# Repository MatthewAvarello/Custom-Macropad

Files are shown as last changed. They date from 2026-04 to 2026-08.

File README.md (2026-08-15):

# Matthew's Lovely Macropad
My macropad is a 9 key macropad with a rotary encoder and an OLED screen! It uses KMK Firmware
## PCB
### Schematic:
The 9 keys are positioned in a 3x3 matrix, saving 3 gpio pins for other use

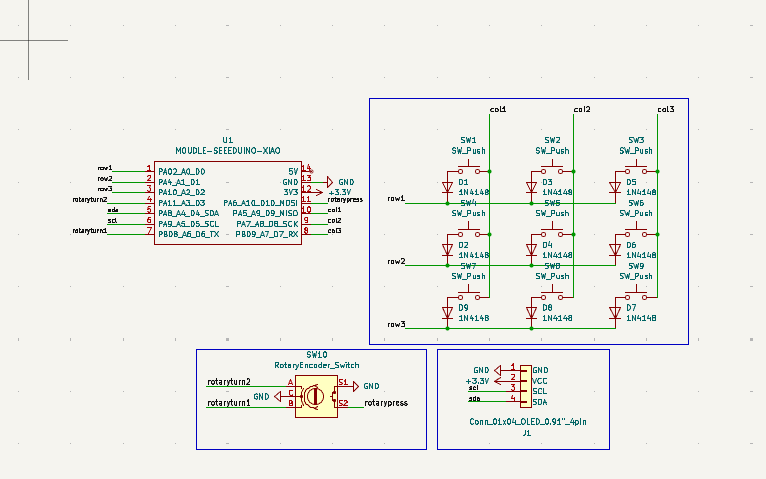
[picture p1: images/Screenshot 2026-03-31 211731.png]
Schematic

### PCB:
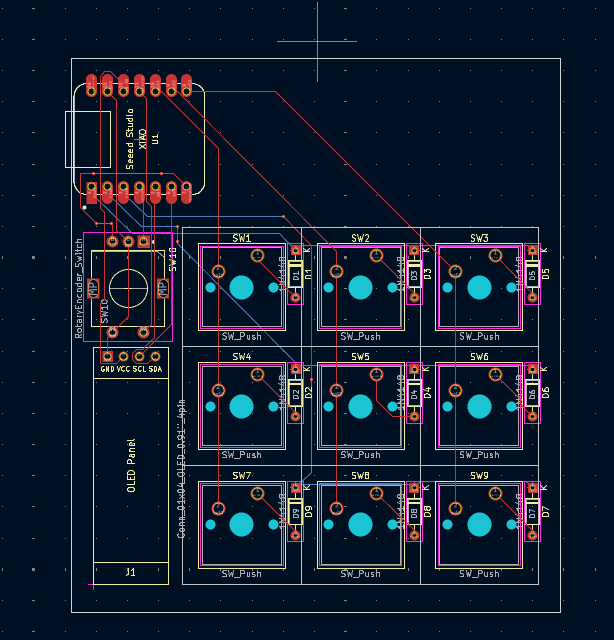
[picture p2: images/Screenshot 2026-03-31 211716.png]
PCB

## CAD:
Two part Case is held by two m3 screws and heatset inserts
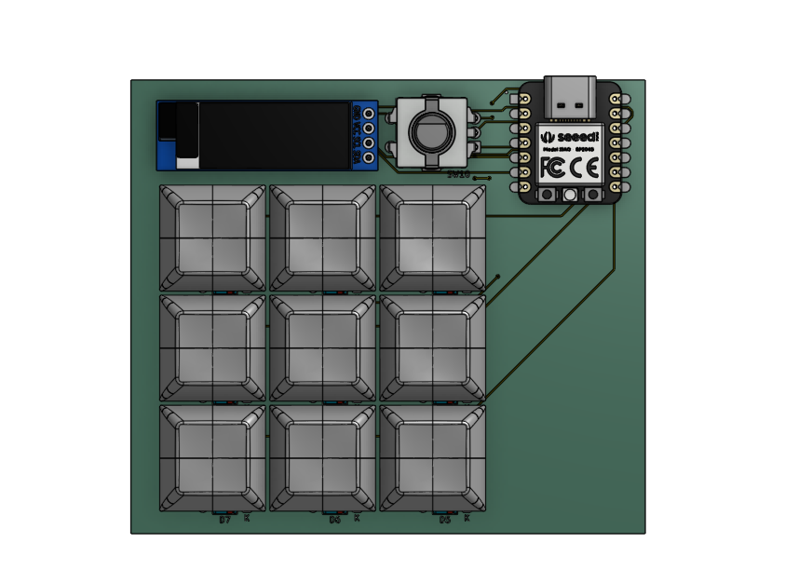
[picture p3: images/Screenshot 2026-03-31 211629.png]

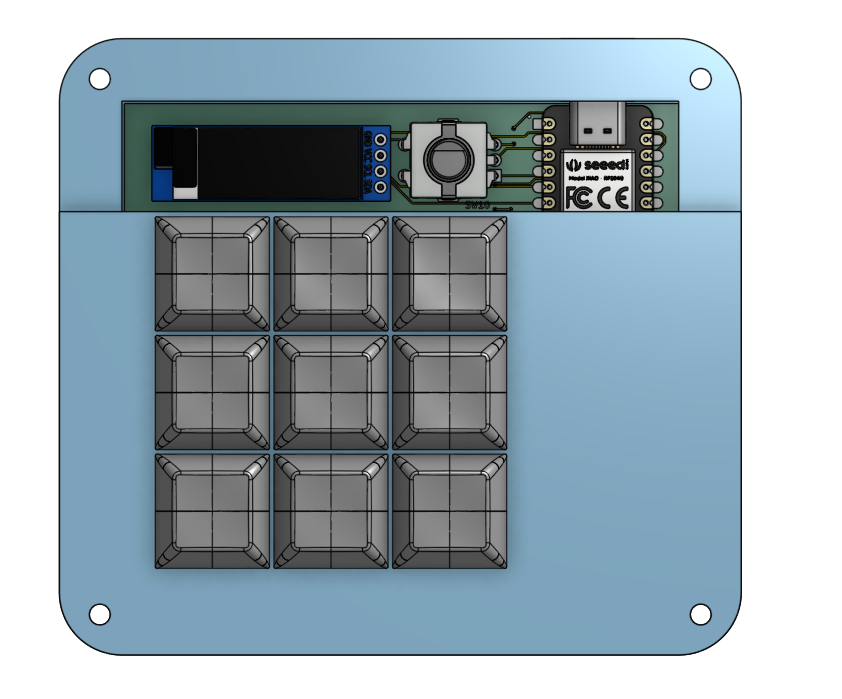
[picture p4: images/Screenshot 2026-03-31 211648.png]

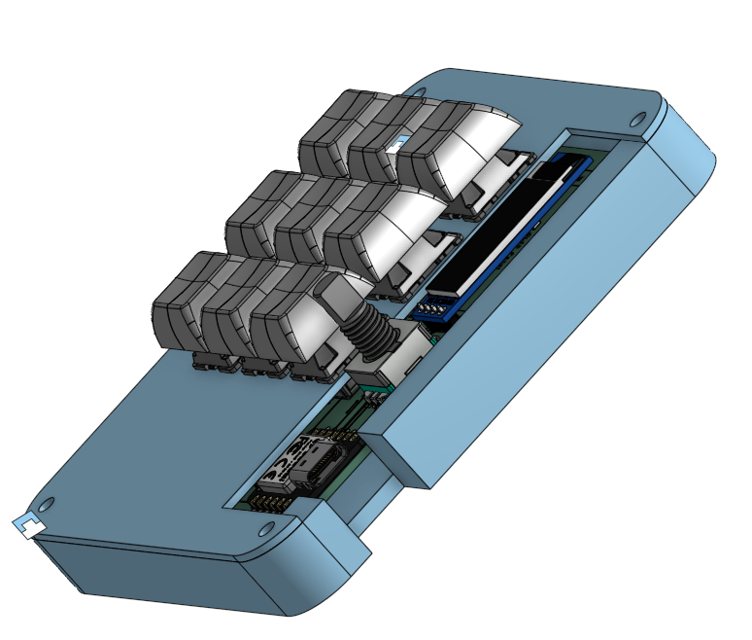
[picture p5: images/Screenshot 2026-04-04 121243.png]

## Firmware:
* Uses KMK Firmware to power the PCB
* Keys act as a numberpad, unless 9 is held, in which the numbers turn into their respective function keys.
* Rotary encoder outputs arrows, button is unbound.
* OLED screen shows whether you are in Normal or function key mode
## BOM
* 9x Cherry MX Switches
* 9x DSA Keycaps
* 2x M3x5x4 HeatSet Inserts
* 2x M3x16mm Screws
* 9x Through the hole 1N4148 Diodes
* 1x 0.91" 128x32 OLED Screen
* 1x EC11E Rotary Encoder
* 1x XIAO RP2040
* 1x The Case (3d Printed Top and Bottom)
* 1x Soldering Iron (Unforunately do not have one)
## Room for Improvement
Looking back I would have changed the following if I had more time.

* Extended the top case print so that the case used 4 screws instead of 2. This would have probably helped structural stability
* Made the keybinds on the firmware more interesting and useful for every day use
* Made the wiring on the PCB more orderly instead of a jumbled mess 💀

## Random Other Notes
CAD was definetely the hardest part for me, arguably took around 80% of the total time I spent on the project. However, it was a great learning experience!

## Gallery
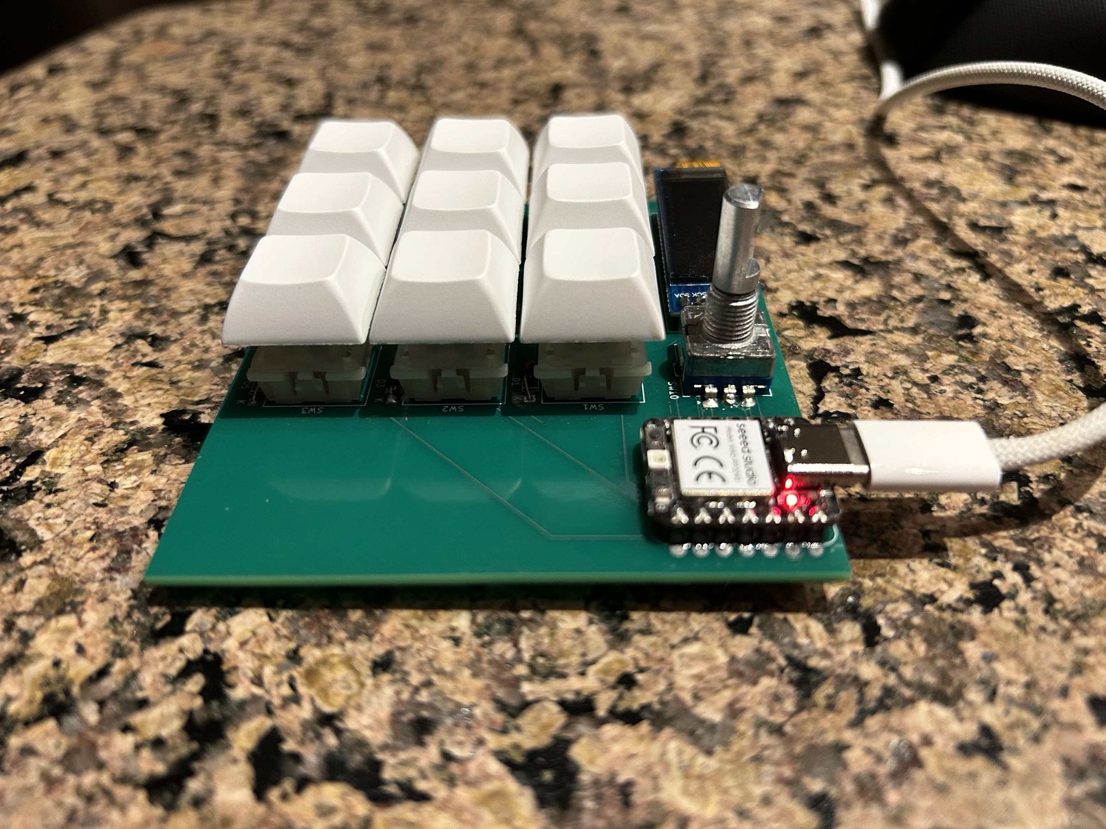
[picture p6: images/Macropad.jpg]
Image of completed real life Macropad on a counter


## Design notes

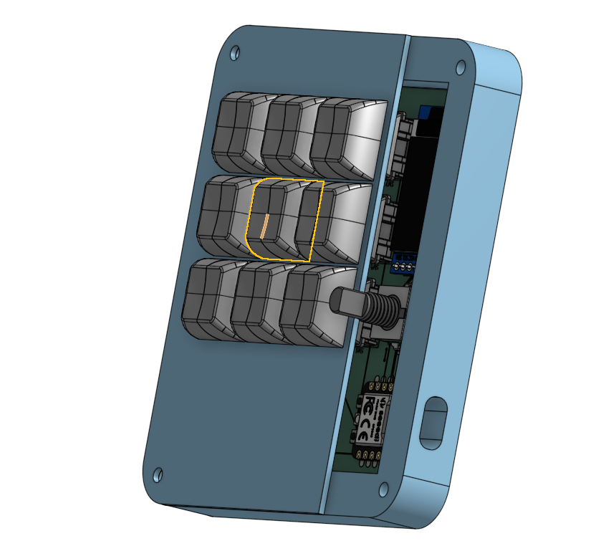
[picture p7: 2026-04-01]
images/Screenshot 2026-03-31 212509.png

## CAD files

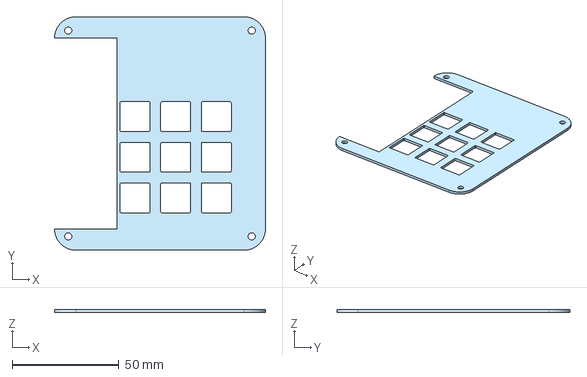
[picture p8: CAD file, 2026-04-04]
Production/Top case (1).step
98.9 x 109.4 x 1.50 mm

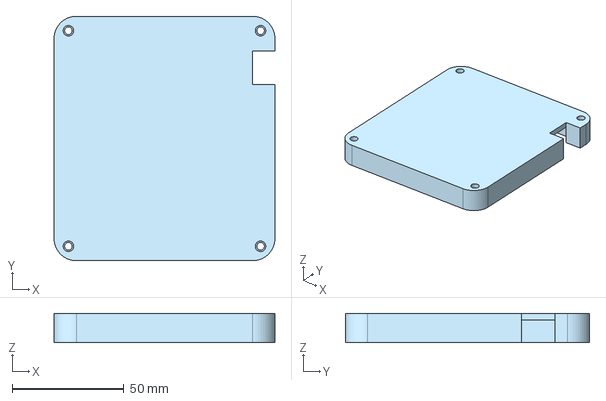
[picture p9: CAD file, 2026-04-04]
Production/Bottom Case (1).step
98.9 x 109.4 x 13.0 mm

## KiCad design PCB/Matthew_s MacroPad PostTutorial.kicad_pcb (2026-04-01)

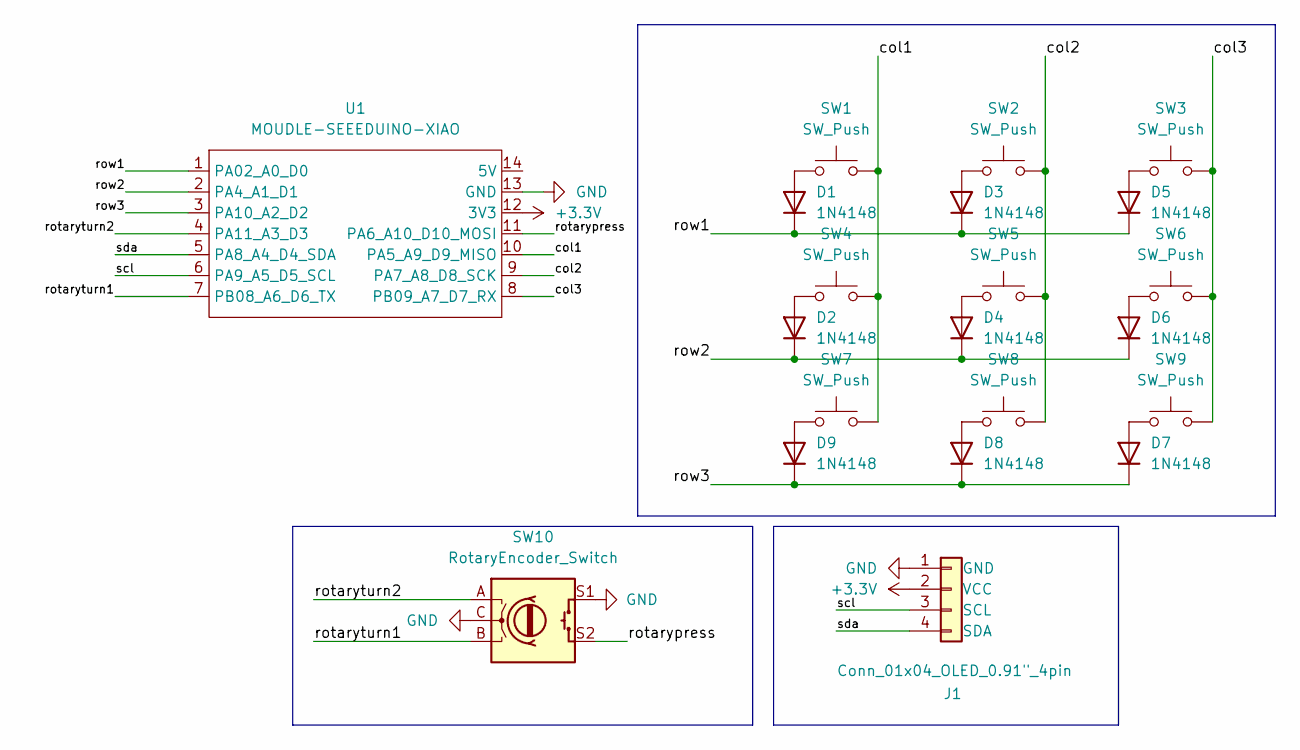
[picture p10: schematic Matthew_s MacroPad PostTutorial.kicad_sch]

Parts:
D1, D2, D3, D4, D5, D6, D7, D8, D9: 1N4148; D_DO-35_SOD27_P7.62mm_Horizontal
J1: Conn_01x04_OLED_0.91"_4pin; SSD1306-0.91-OLED-4pin-128x32
SW1, SW2, SW3, SW4, SW5, SW6, SW7, SW8, SW9: SW_Push; SW_Cherry_MX_1.00u_PCB
SW10: RotaryEncoder_Switch; RotaryEncoder_Alps_EC11E-Switch_Vertical_H20mm
U1: MOUDLE-SEEEDUINO-XIAO; XIAO-Generic-Hybrid-14P-2.54-21X17.8MM

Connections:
+3.3V: J1.2 (VCC), U1.12 (3V3)
/col1: SW1.2, SW4.2, SW7.2, U1.10 (PA5_A9_D9_MISO)
/col2: SW2.2, SW5.2, SW8.2, U1.9 (PA7_A8_D8_SCK)
/col3: SW3.2, SW6.2, SW9.2, U1.8 (PB09_A7_D7_RX)
/rotarypress: SW10.S2, U1.11 (PA6_A10_D10_MOSI)
/rotaryturn1: SW10.B, U1.7 (PB08_A6_D6_TX)
/rotaryturn2: SW10.A, U1.4 (PA11_A3_D3)
/row1: D1.1 (K), D3.1 (K), D5.1 (K), U1.1 (PA02_A0_D0)
/row2: D2.1 (K), D4.1 (K), D6.1 (K), U1.2 (PA4_A1_D1)
/row3: D7.1 (K), D8.1 (K), D9.1 (K), U1.3 (PA10_A2_D2)
/scl: J1.3 (SCL), U1.6 (PA9_A5_D5_SCL)
/sda: J1.4 (SDA), U1.5 (PA8_A4_D4_SDA)
GND: J1.1 (GND), SW10.C, SW10.S1, U1.13 (GND)
unnamed: D1.2 (A), SW1.1
unnamed: D2.2 (A), SW4.1
unnamed: D3.2 (A), SW2.1
unnamed: D4.2 (A), SW5.1
unnamed: D5.2 (A), SW3.1
unnamed: D6.2 (A), SW6.1
unnamed: D7.2 (A), SW9.1
unnamed: D8.2 (A), SW8.1
unnamed: D9.2 (A), SW7.1

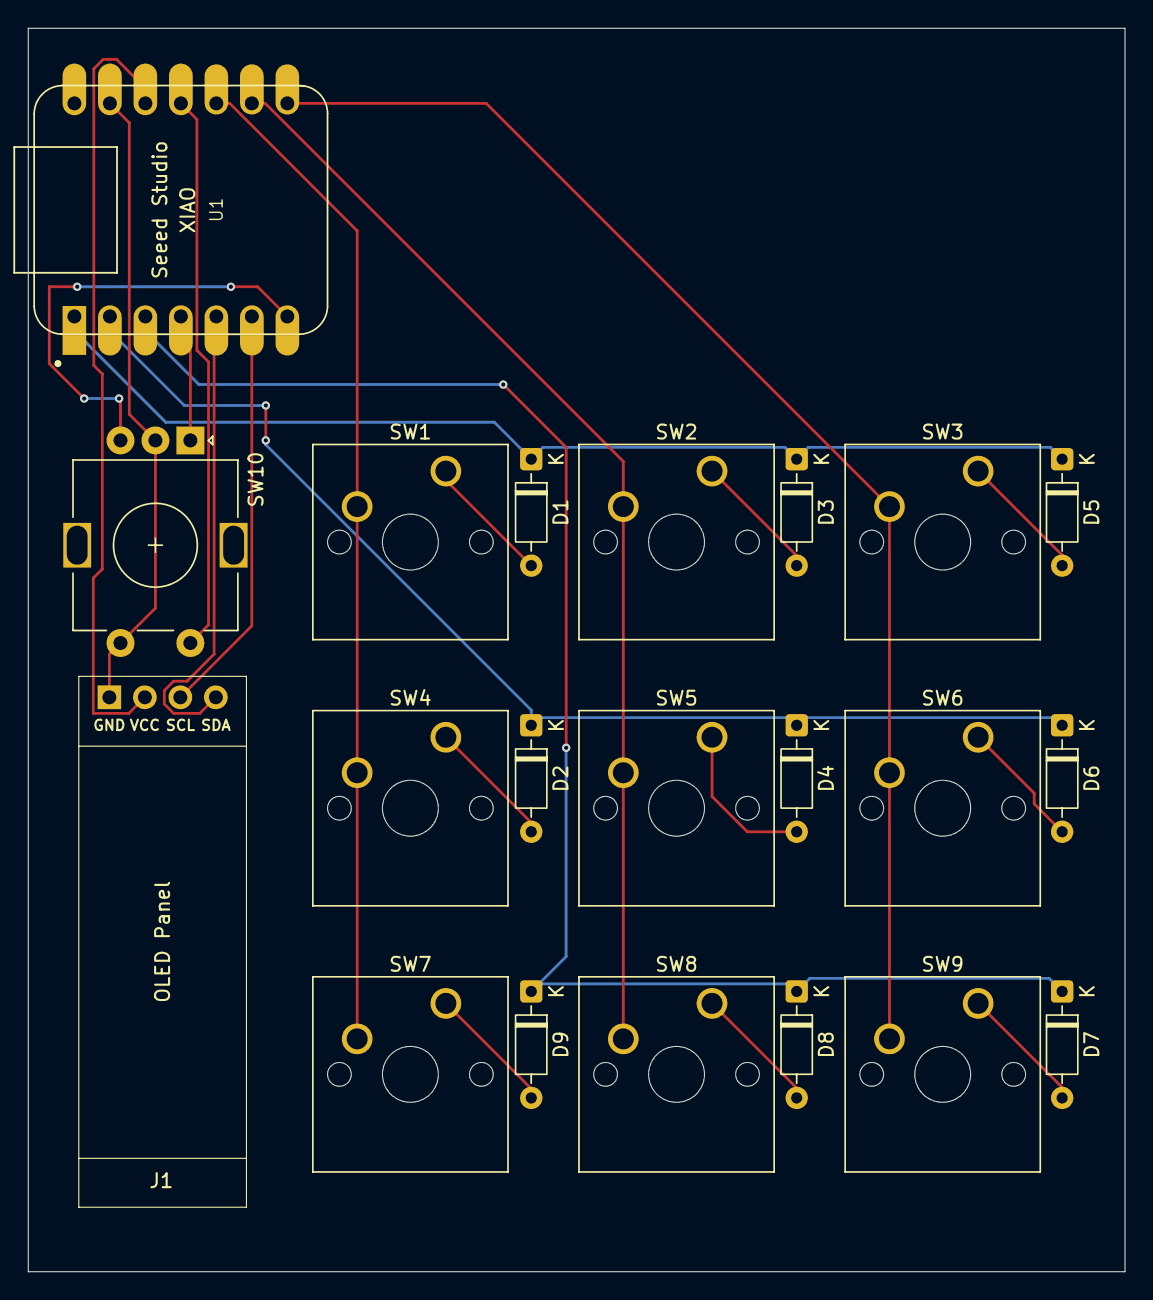
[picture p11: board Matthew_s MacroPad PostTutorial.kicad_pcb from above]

Board: 2 copper layers, 78.5 x 89.0 mm, 21 parts (0 on the bottom side), 22 nets.

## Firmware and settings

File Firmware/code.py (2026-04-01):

import board
from kmk.kmk_keyboard import KMKKeyboard
from kmk.keys import KC
from kmk.scanners.keypad import KeyMatrixScanner
from kmk.modules.layers import Layers
from kmk.modules.encoder import EncoderHandler
from kmk.extensions.peg_oled_display import Oled, OledDisplayMode, OledReactionType, OledData

keyboard = KMKKeyboard()

keyboard.scanner = KeyMatrixScanner(
    row_pins=(board.A0, board.A1, board.A2),
    col_pins=(board.A5, board.A7, board.A8),
    columns_to_anodes=True,
)

layers = Layers()
keyboard.modules.append(layers)

encoder = EncoderHandler()
encoder.pins = ((board.A3, board.TX, board.A10, False),)
keyboard.modules.append(encoder)

oled = Oled(
    OledData(
        corner_one={0: OledReactionType.STATIC, 1: ['BASE']},
        corner_two={0: OledReactionType.LAYER, 1: ['BASE', 'FN']},
        corner_three={0: OledReactionType.STATIC, 1: ['ENC:ARW']},
        corner_four={0: OledReactionType.LAYER, 1: ['ENC:ARW', 'ENC:VOL']},
    ),
    toDisplay=OledDisplayMode.TXT,
    flip=False,
)
keyboard.extensions.append(oled)

MO1 = KC.MO(1)

keyboard.keymap = [
    [
        KC.N1,  KC.N2,  KC.N3,
        KC.N4,  KC.N5,  KC.N6,
        KC.N7,  KC.N8,  MO1,
    ],
    [
        KC.F1,   KC.F2,   KC.F3,
        KC.MUTE, KC.VOLD, KC.VOLU,
        KC.TRNS, KC.TRNS, KC.TRNS,
    ],
]

encoder.map = [
    ((KC.LEFT, KC.RIGHT),),
    ((KC.VOLD, KC.VOLU),),
]

if __name__ == '__main__':
    keyboard.go()

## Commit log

2026-04-01 Project Ready for Submission
    [Bottom Case.step, Matthew_s MacroPad PostTutorial.kicad_pcb, Matthew_s MacroPad PostTutorial.kicad_sch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]
2026-04-01 Fix typo in CAD time description
    Corrected a typo in the README regarding CAD time spent.
2026-04-04 Fixed Switch alignment issue
    [Bottom Case (1).step, Bottom Case.step, Top case (1).step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]
